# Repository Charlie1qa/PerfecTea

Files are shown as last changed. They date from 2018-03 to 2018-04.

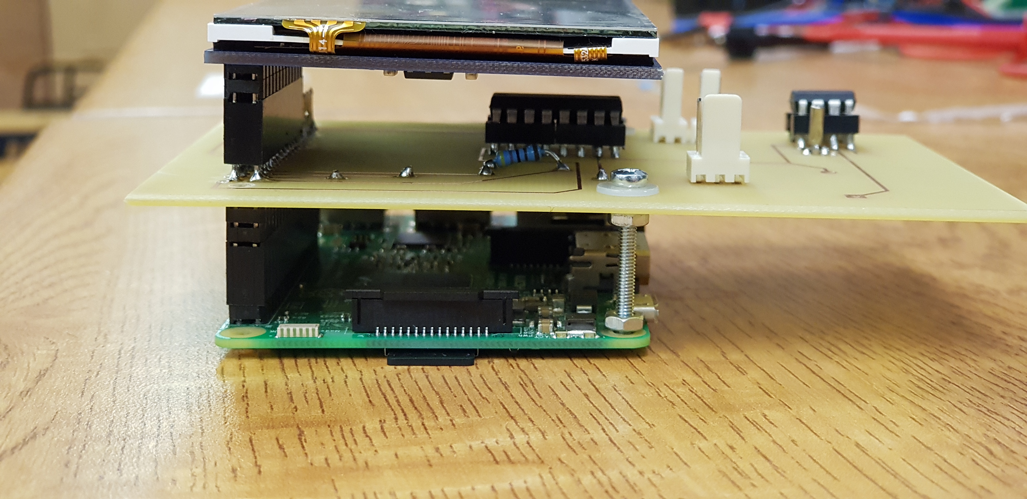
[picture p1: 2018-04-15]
img/PCB_side.jpg

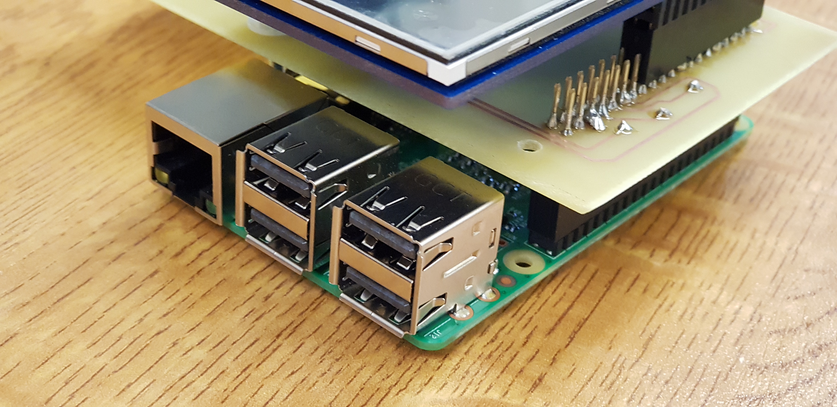
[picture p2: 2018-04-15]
img/PCB_isometric.jpg

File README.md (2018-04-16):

# PerfectTea

### The Quest To Create the Perfect Cup of Tea!!

In 2018 we have tried to solved several of the worlds biggest problems, we have cars in space, we can order pizza online and have it delivered to our doors but we have one last limitation to overcome.....a good....no wait...Perfect cup of tea! Follow the adventure at https://twitter.com/Perfec_Tea . Check out our video at https://www.youtube.com/watch?v=b-V9AOYMbWo

## How?

The machine is based upon a paper by the BSA to create the ideal cup of tea, to be used to compare different tea types. From this we have developed a way to create your ideal brew in 3 strengths. 

Place your tea into the infuser. Add hot water into your regular ~~viking horn~~ cup and placed in the machine. You select your required strength and size of cup, then you relax and let the machine take care of the rest. Add milk to taste. 

For more detailled instructions on how to build PerfecTea please see our Wiki.  

### Software Flow Diagram



### GUI Mock Ups

Start Screen:



Menu:



### Early Designs:




### Prototype Frame



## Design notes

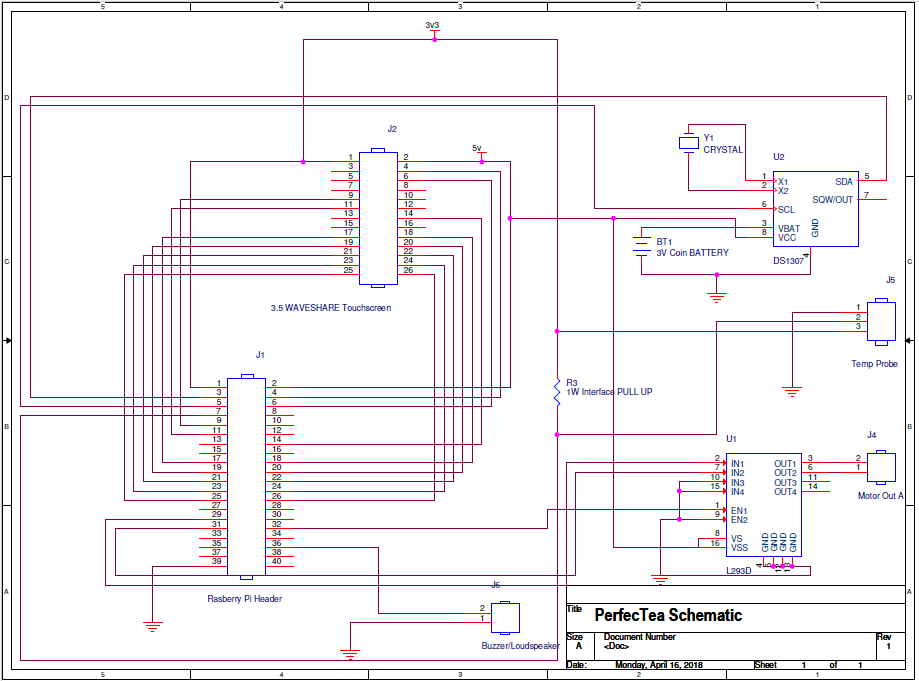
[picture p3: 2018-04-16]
img/Schematic.png

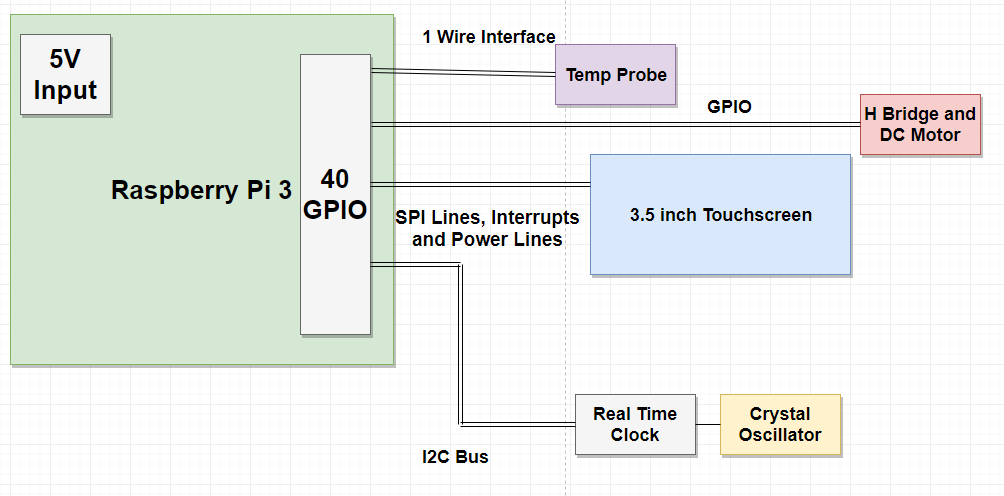
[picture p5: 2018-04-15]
img/SystemBlockDiagram.PNG

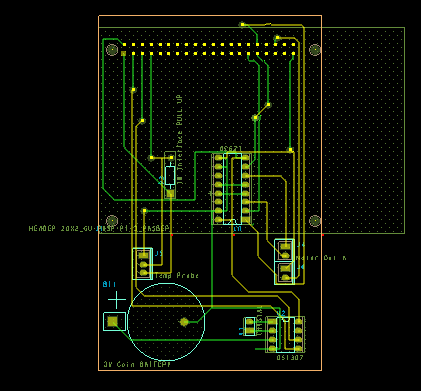
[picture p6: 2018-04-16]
img/PCB.PNG

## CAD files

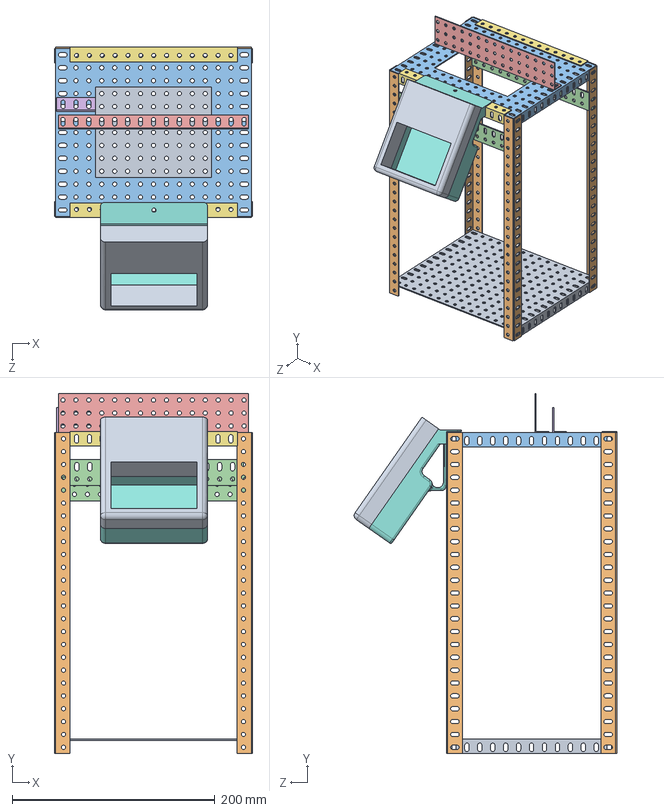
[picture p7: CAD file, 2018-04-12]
cad/Perfectea.SLDASM
195.5 x 355.1 x 259.1 mm
base_plate
vertical_struct x 4
top_plate
Horizontal_suppot x 2
motor_braket
cog_supportSLDPRT
top_border x 2
Real_time_case
real_time_lid

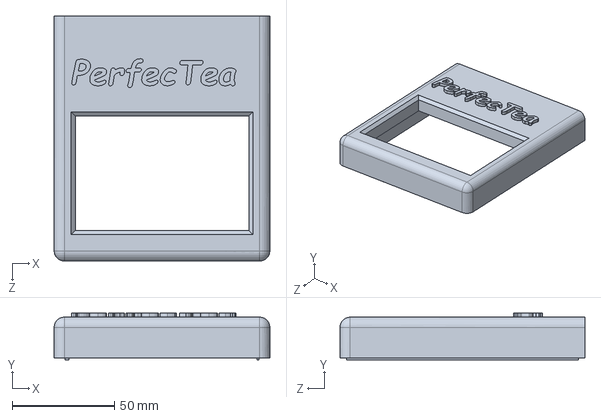
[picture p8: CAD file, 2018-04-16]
cad/real_time_lid_3.SLDPRT
105.7 x 23.0 x 120.0 mm

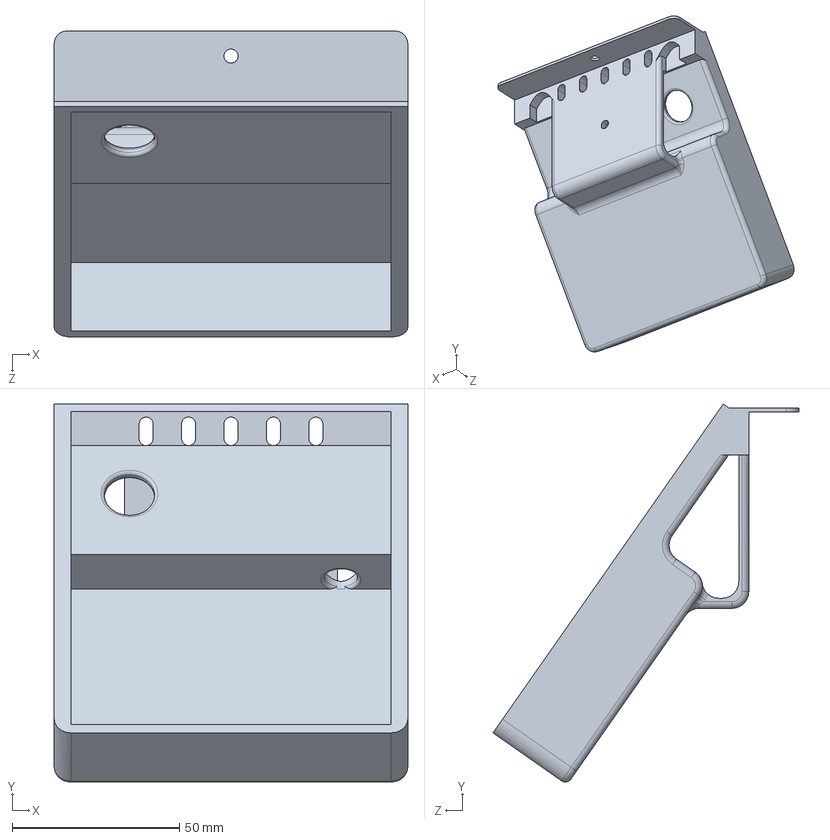
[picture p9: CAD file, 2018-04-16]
cad/Real_time_case_3.SLDPRT
105.7 x 113.0 x 91.5 mm

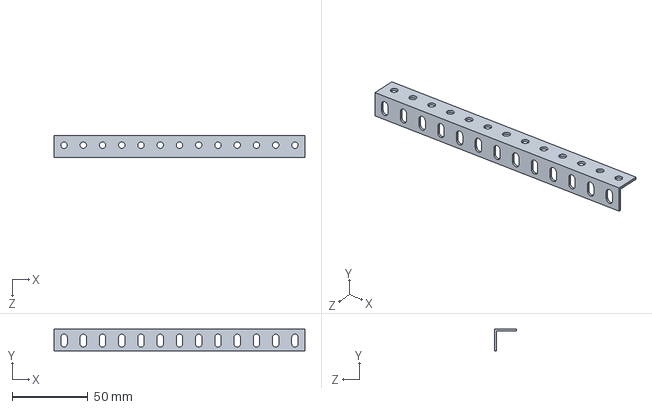
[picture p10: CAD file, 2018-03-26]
cad/top_border.SLDPRT
165.4 x 14.3 x 14.6 mm

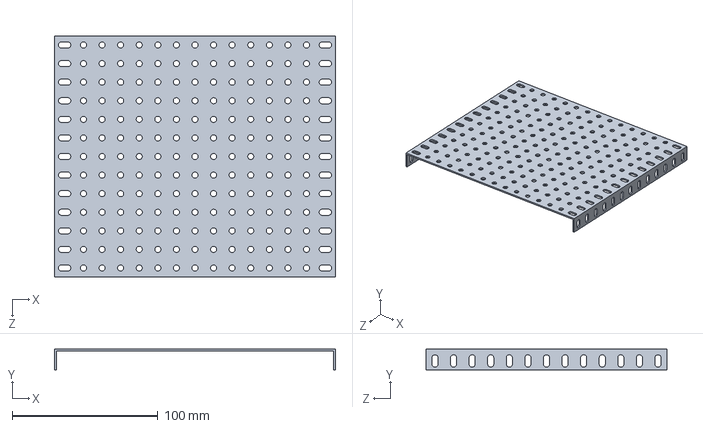
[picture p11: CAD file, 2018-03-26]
cad/base_plate.SLDPRT
192.9 x 14.2 x 165.6 mm

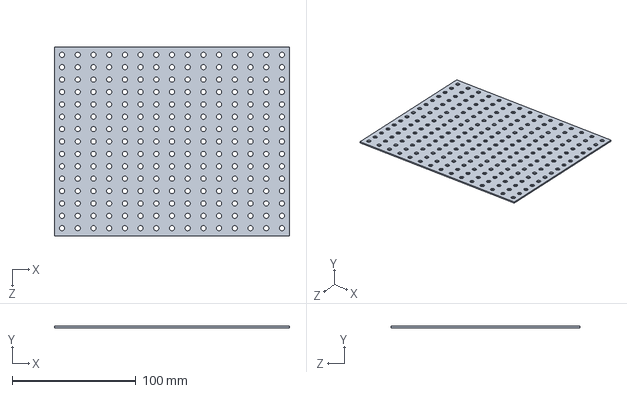
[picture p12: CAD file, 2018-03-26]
cad/Part4.SLDPRT
189.7 x 1.30 x 152.2 mm

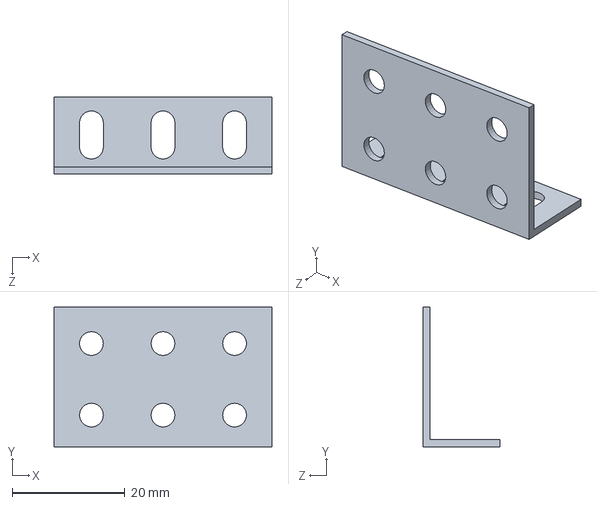
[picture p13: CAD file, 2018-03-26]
cad/cog_supportSLDPRT.SLDPRT
38.6 x 24.7 x 13.7 mm

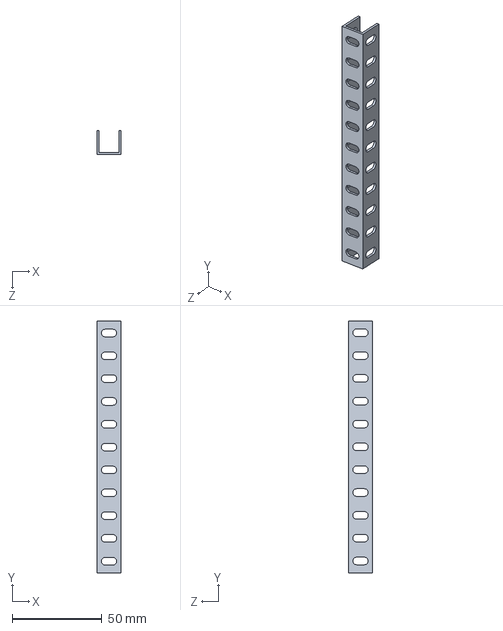
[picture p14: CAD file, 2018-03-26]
cad/casset_edging.SLDPRT
13.5 x 140.0 x 13.5 mm

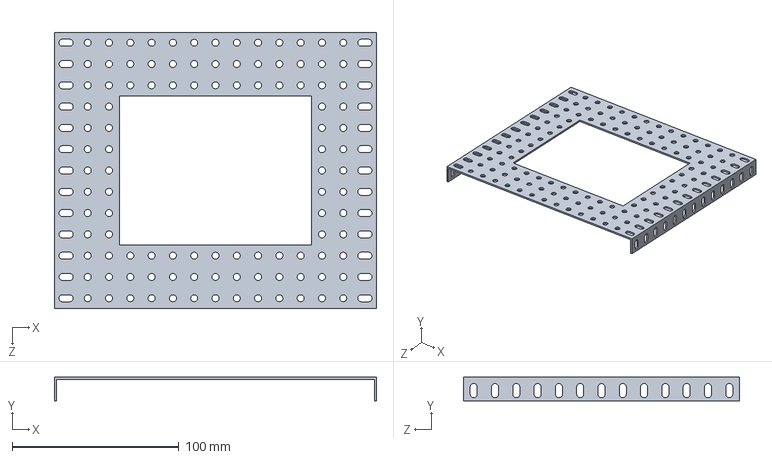
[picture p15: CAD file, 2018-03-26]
cad/top_plate.SLDPRT
192.9 x 14.2 x 165.6 mm

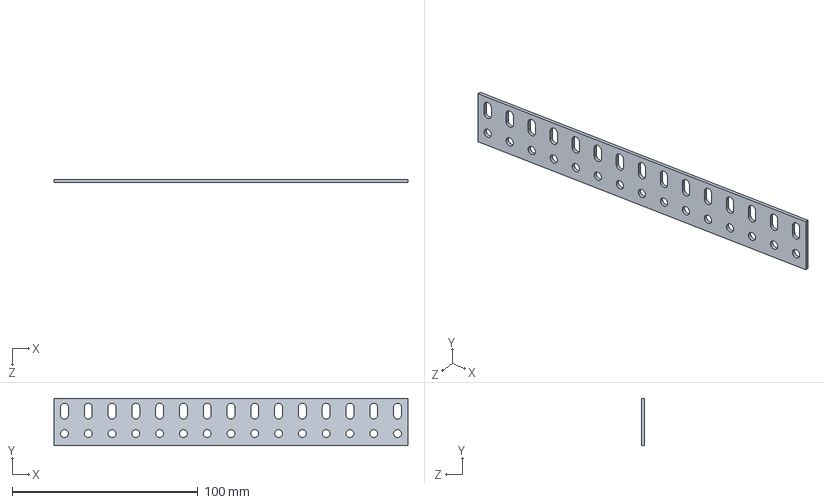
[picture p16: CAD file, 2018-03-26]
cad/Horizontal_suppot.SLDPRT
190.5 x 25.4 x 1.64 mm

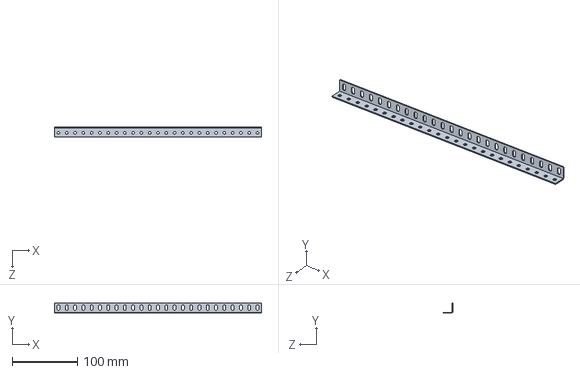
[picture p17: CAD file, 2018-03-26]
cad/vertical_struct.SLDPRT
316.5 x 15.7 x 15.3 mm

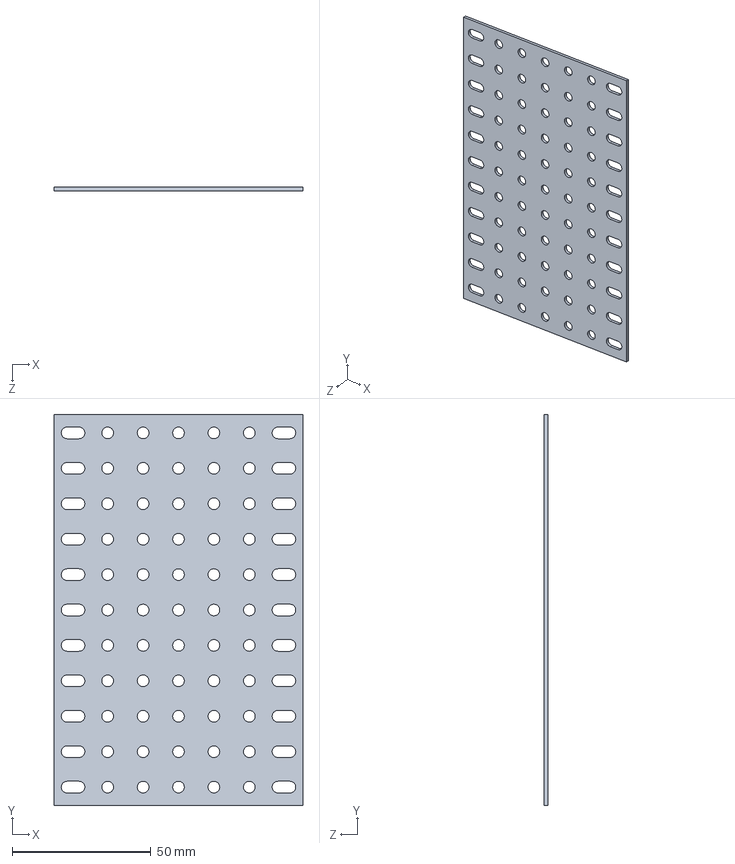
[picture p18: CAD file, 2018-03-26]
cad/casset_casing.SLDPRT
89.6 x 140.9 x 1.30 mm

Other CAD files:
cad/Part1.SLDPRT
PerfecTea Schematic and PCB Design/footprints/psmpath/gu-header26.psm
PerfecTea Schematic and PCB Design/footprints/psmpath/gu-rasp-pi-3.psm
cad/Perfectea.SLDDRW

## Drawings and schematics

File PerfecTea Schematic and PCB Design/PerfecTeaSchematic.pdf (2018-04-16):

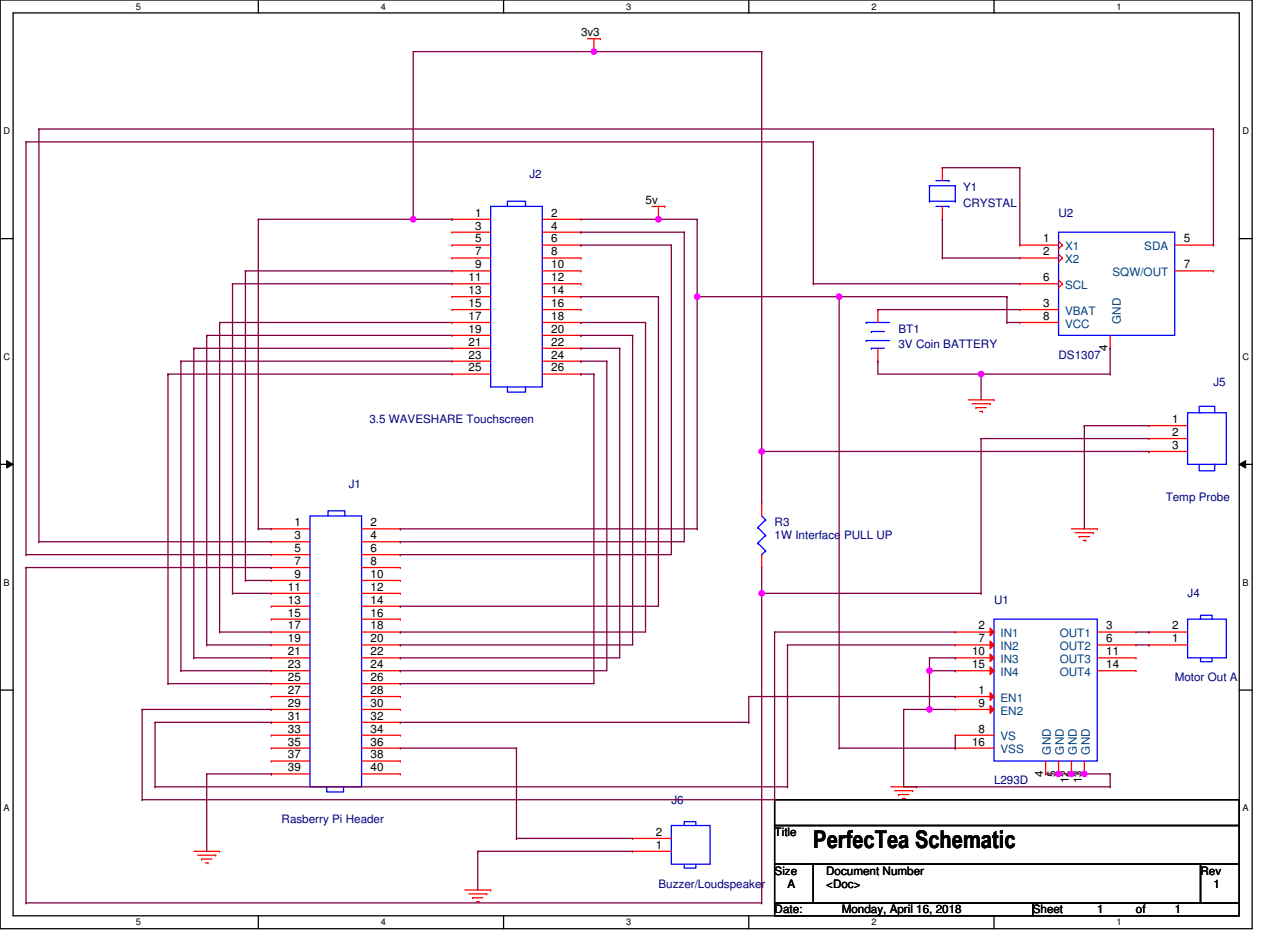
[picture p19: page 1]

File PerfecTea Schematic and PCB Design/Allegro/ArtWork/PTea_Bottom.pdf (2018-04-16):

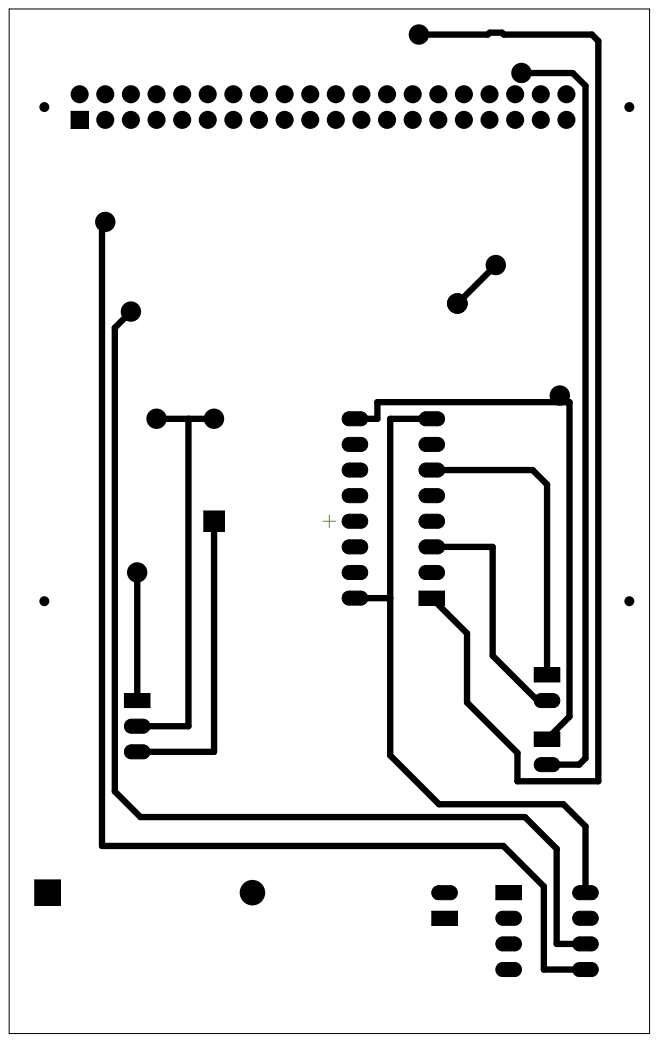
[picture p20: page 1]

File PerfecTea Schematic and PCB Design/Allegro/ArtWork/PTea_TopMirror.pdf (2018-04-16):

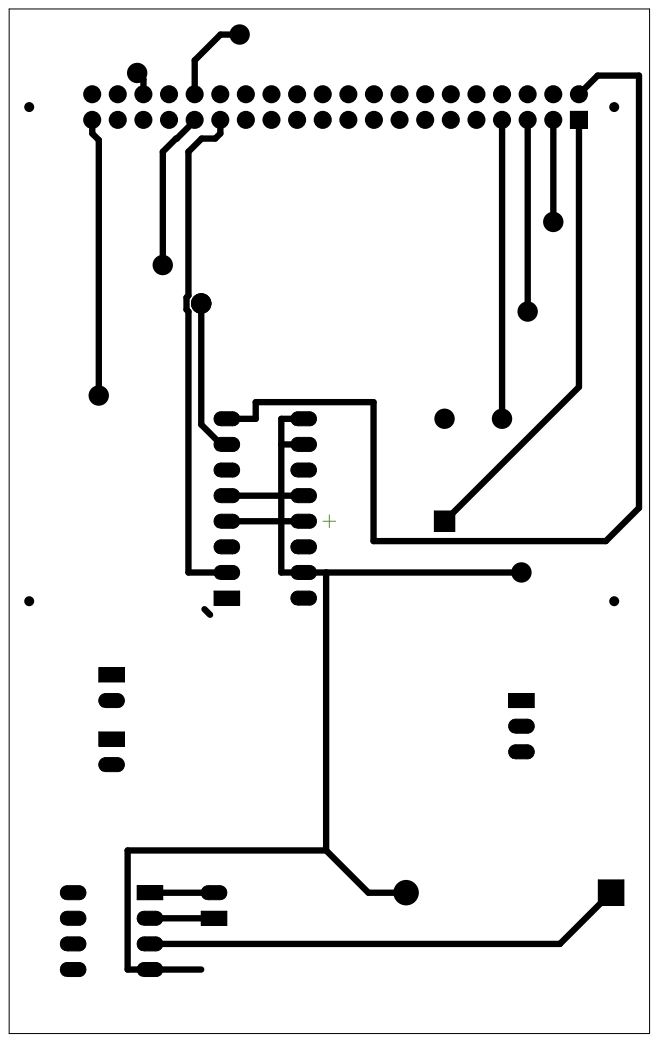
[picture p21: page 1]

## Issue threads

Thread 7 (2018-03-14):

Commit messages

2073036n, 2018-03-14:
Some of the commit messages seem to be quite informal or unhelpful (e.g. 'used to work now doesn't, need to figure out why'), maybe try using more meaningful commit messages to ensure that you keep track of the project state and can easily find errors later in the project / roll back to a known state.

Team 11

Charlie1qa, 2018-03-17:
We will use more meaningful commit messages in future commits. Thank you

Closed 2018-03-17.

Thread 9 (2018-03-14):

Software Improvements etc.

2077762b, 2018-03-14:
This project looks like it is progressing well. A few possible improvements include:
* Converting the C code to C++ so that it can make use of the object orientated paradigm.
* Appropriate commenting in the code such that it is easy to understand the purpose of each function.
* Adding PCB board files in addition to the schematic files which have been included.
* Meaningful commit message. Messages such as "fixed" are not helpful. Ideally they should explain which files have been edited and why.
* It would still be quite difficult to replicate the project without further instructions on assembling the mechanical structure.

**Team 10**

Charlie1qa, 2018-03-17:
We will improve on our commenting and commit messages. The PCB board files/ artwork will be uploaded when completed. And more detailed files concerning the chassis will be uploaded.

Closed 2018-03-26.

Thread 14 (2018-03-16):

Unclear components

SimoneMarcigaglia, 2018-03-16:
The drawing in your README file mentions a solenoid valve, but that is not included in your component list. More details on the components used (Protocols and specs) could be useful.

- Team 3

MartinCusack, 2018-03-19:
Those sketches were concepts and the solenoid has been replaced with a motor and chain drive.  We will enevour to make our components list easier to use

Closed 2018-03-26.

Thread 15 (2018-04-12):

Order Of Menu

Charlie1qa, 2018-04-12:
In the main screen should ask for Brew Strength then Cup Size so it flows from top to bottom

BoKarolis, 2018-04-15:
Swapped options around.

Closed 2018-04-15.

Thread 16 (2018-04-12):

CAD Models

Charlie1qa, 2018-04-12:
Need to upload the CAD of the chassis and of the enclosure box

MartinCusack, 2018-04-15:
Full assembly as well as all used components have been added.

Closed 2018-04-15.

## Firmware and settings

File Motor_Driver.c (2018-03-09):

#include <stdio.h> //should be the only needed library as this code will just use standard I/O pins to control motor direction
#include <wiringPi.h>
void pset(){
      pinMode (0, OUTPUT) ; 
      pinMode (1, OUTPUT) ; 

}


int main(){
  if (wiringPiSetup () == -1)
    return 1 ;
    
    pset();   //sets the output GPIO pins needed to send control the motor
    
    //set the IO pin going to Pin 1 of the L293DNE in order to activate the 
  
    //IO pin going to pin 2 set high in order to move the motor in one direction
    
    //wait for 5 seconds 
    
    //stop



}

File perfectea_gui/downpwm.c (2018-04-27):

#include <wiringPi.h>
#include <softPwm.h>
#include <stdio.h>

// 0- Stop, 1- Down, 2- Up


int main() {
  wiringPiSetup();

  pinMode (21, OUTPUT) ;
  pinMode (22, OUTPUT) ;
 
  softPwmCreate (26, 0, 100); //int pin, int initialValue, int pwmRange

	  digitalWrite(21,HIGH) ; 
	  digitalWrite(22,LOW) ; 
          softPwmWrite (26, 100);

long int count = 0;


while(count<20000000){
count++;
}
}

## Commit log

2018-02-19 Create Motor Drive
2018-02-20 Initial Schematic Design
    [REALTIME.DSN]
2018-03-05 Initial Temp Probe Program
2018-03-06 Update Motor Drive
2018-03-08 Added Motor Driving Program, Worked at first, now doesn't need to work out why? :-(
    [test.c]
2018-03-09 Updated Schematic Diagrams
    Fixed 1 Wire connections and updated pinouts between RPi and Screen
    [REALTIME.DSN]
2018-03-17 System Flow Chart Version 1
    Describes the operation of the GUI screens and user interface options.
2018-03-25 PDF Version of Schematic
2018-03-26 CAD parts
    this file contains the cad models of all the parts used in the construction of the with assembly to follow
    [Horizontal_suppot.SLDPRT, Part1.SLDPRT, Part4.SLDPRT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]
2018-03-26 PCB Layouts
    [PerfecTea_rev_1.brd, largerbrd.brd, rev1.brd]
2018-03-26 Added Raspberry Pi footprints for Cadence OrCAD
    [gu-rasp-pi-3.psm]
2018-03-26 Updated Schematics with footprints
    [REALTIME.DSN]
2018-04-12 Overall 3D PDF view of the assembled chassis
2018-04-12 Final CAD engineering drawing of full assembly
    [Perfectea.SLDDRW]
2018-04-15 Added PNG file of schematic design so it is easier to upload to Wiki
2018-04-15 PNG Files of Assembled Chassis CAD Model
2018-04-15 added temperature checking
2018-04-15 PCB images both side and isometric views
2018-04-15 motor control testing
2018-04-16 testing motor control
2018-04-16 testing motor operation
2018-04-16 Fixed Issues with Rev 1 Schematic and PCB
    Connections between L293S inputs and RPi where grounded (physical pins 30 and 43). These where moved to 29 and 31 on the opposite side of the GPIO header. Also includes the updated PCB design files and ArtWorks. Also fixed a track which connected to the PCB header on the bottom side (which was awkward to solder), moved this track to the top side of the etching layer.
    [PerfecTea_rev_1.brd, PerfecTea_rev_1.dsn, PerfecTea_rev_2-Template.brd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]
2018-04-16 Updated schematic with recent changes (see PCB files upload)
2018-04-16 Updated PCB and schematic images
2018-04-16 The final case parts which were 3D printed
    [Real_time_case_3.SLDPRT, real_time_lid_3.SLDPRT]
2018-04-16 added motor control scripts
